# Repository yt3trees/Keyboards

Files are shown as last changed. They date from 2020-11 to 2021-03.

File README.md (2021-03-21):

# Limb44
Limb44, a split keyboard with 3x6 column staggered keys and 4 thumb keys.
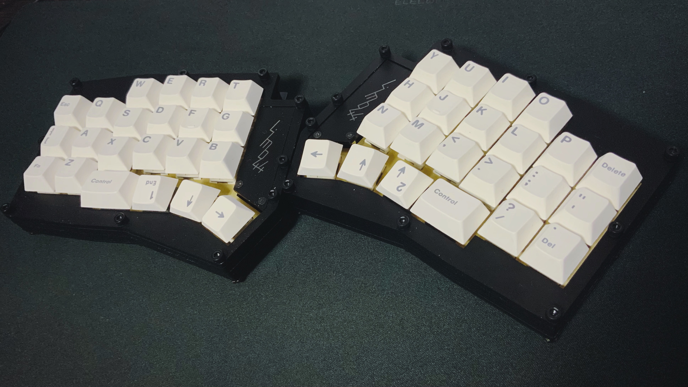
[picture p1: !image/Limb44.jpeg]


# Beryl32
Beryl32, a keyboard with 3x10 column staggered keys and 2 thumb keys.

Keyboard Maintainer: [yt3trees](https://github.com/yt3trees/)  [@yt3trees](https://twitter.com/yt3trees)
Firmware: [keyboards/limb44](https://github.com/yt3trees/qmk_firmware/tree/master/keyboards/limb44)

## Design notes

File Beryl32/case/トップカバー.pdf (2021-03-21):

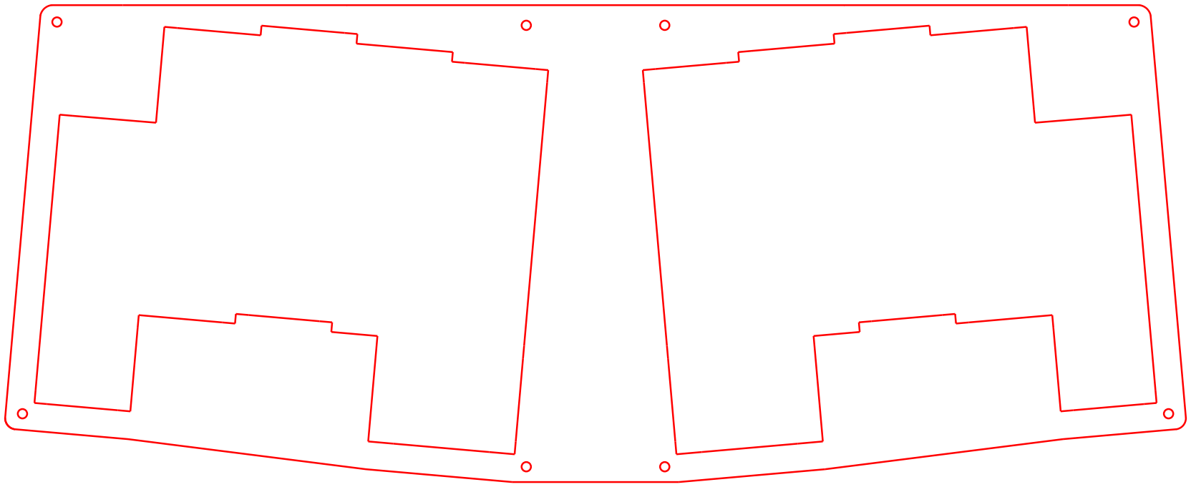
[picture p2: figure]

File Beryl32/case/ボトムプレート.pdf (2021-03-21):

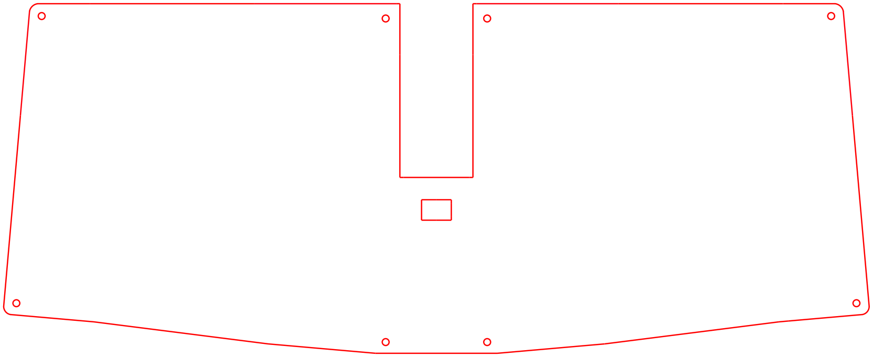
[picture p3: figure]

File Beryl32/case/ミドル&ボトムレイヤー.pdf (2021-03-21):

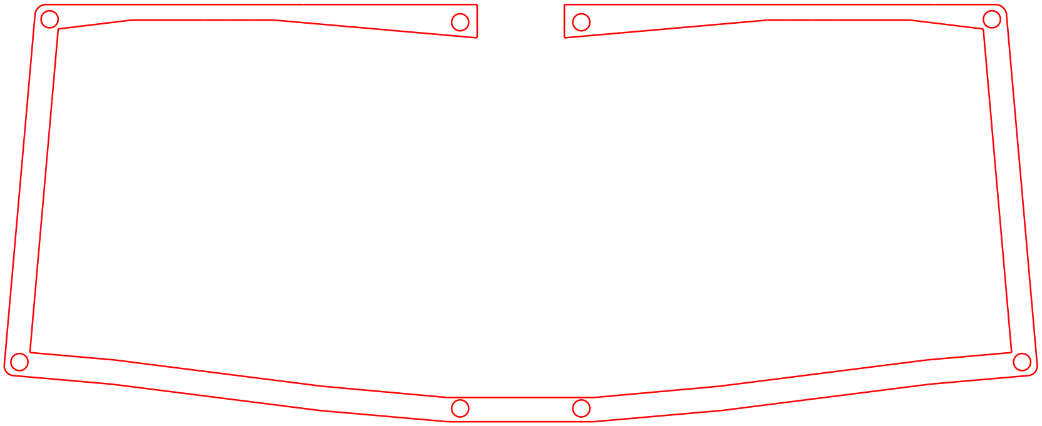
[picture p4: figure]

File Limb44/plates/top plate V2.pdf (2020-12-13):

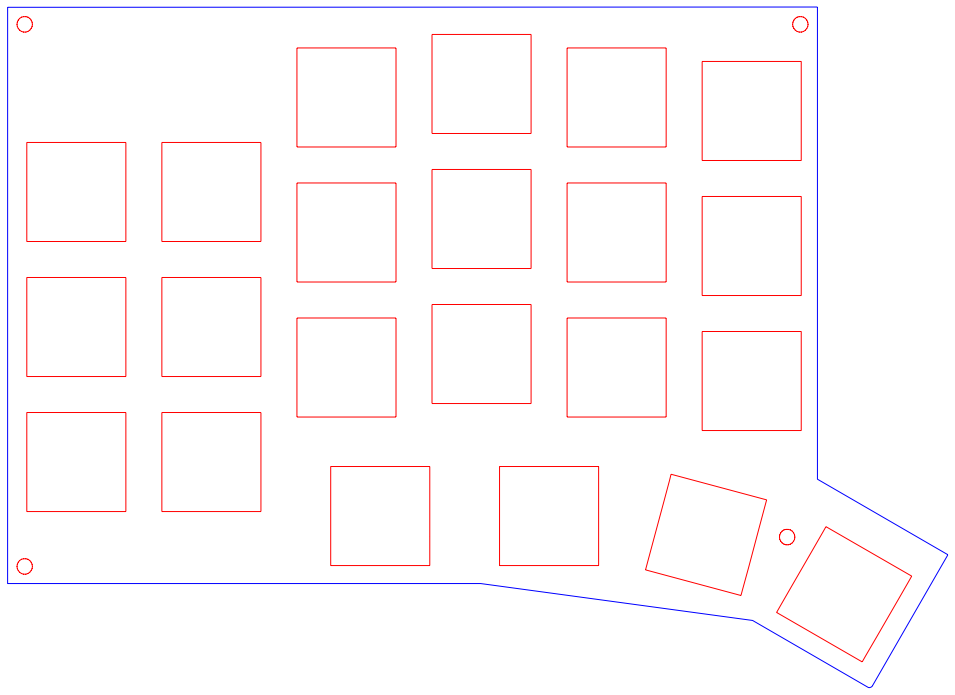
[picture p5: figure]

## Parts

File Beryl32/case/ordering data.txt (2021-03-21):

①トップカバー.pdf
　枚数：1枚
　カラー：ガラス色マット
　厚さ：5mm
　切断処理：鏡面仕上げ

②ミドル&ボトムレイヤー.pdf
　枚数：1枚
　カラー：ガラス色
　厚さ：5mm
　切断処理：鏡面仕上げ

③ミドル&ボトムレイヤー.pdf
　枚数：1枚
　カラー：ガラス色
　厚さ：2mm
　切断処理：鏡面仕上げ

④ボトムプレート.pdf
　枚数：1枚
　カラー：ガラス色マット
　厚さ：2mm
　切断処理：鏡面仕上げ

------
※②と③は同じpdfファイルです。

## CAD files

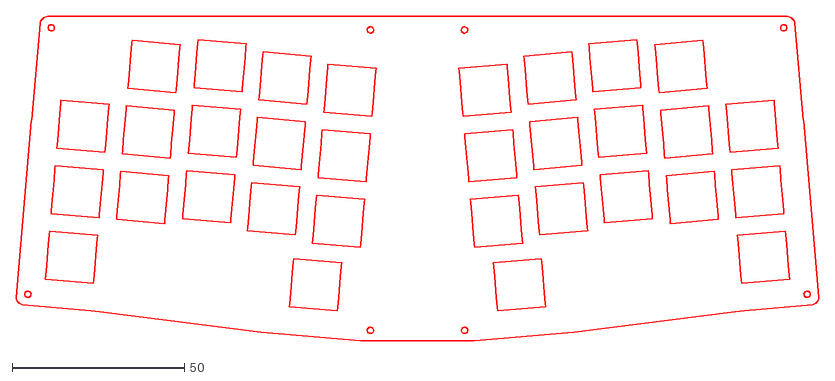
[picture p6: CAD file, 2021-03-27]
Beryl32/case/切断堂/マウントプレート.dxf
232.8 x 94.0

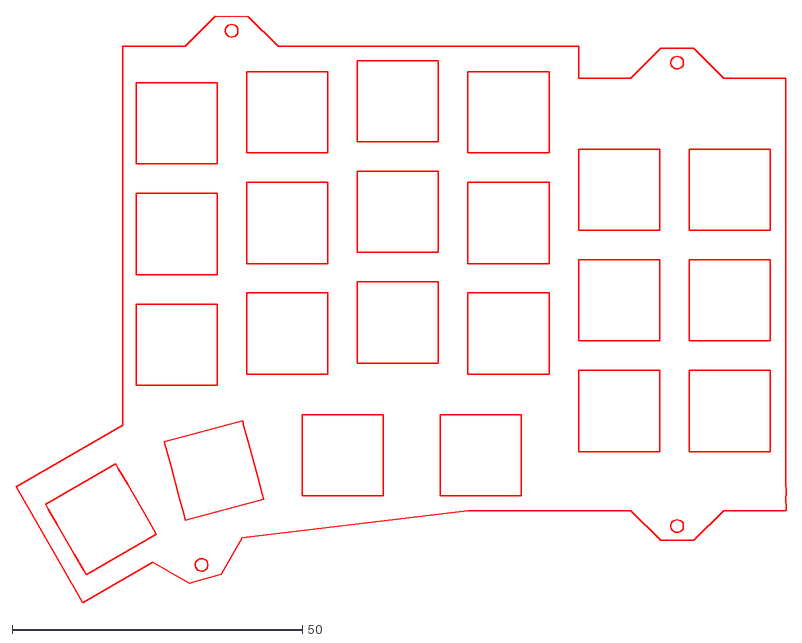
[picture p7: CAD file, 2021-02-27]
Limb44/plates/アクリル積層ver/V2/マウントプレート.dxf
132.6 x 100.9

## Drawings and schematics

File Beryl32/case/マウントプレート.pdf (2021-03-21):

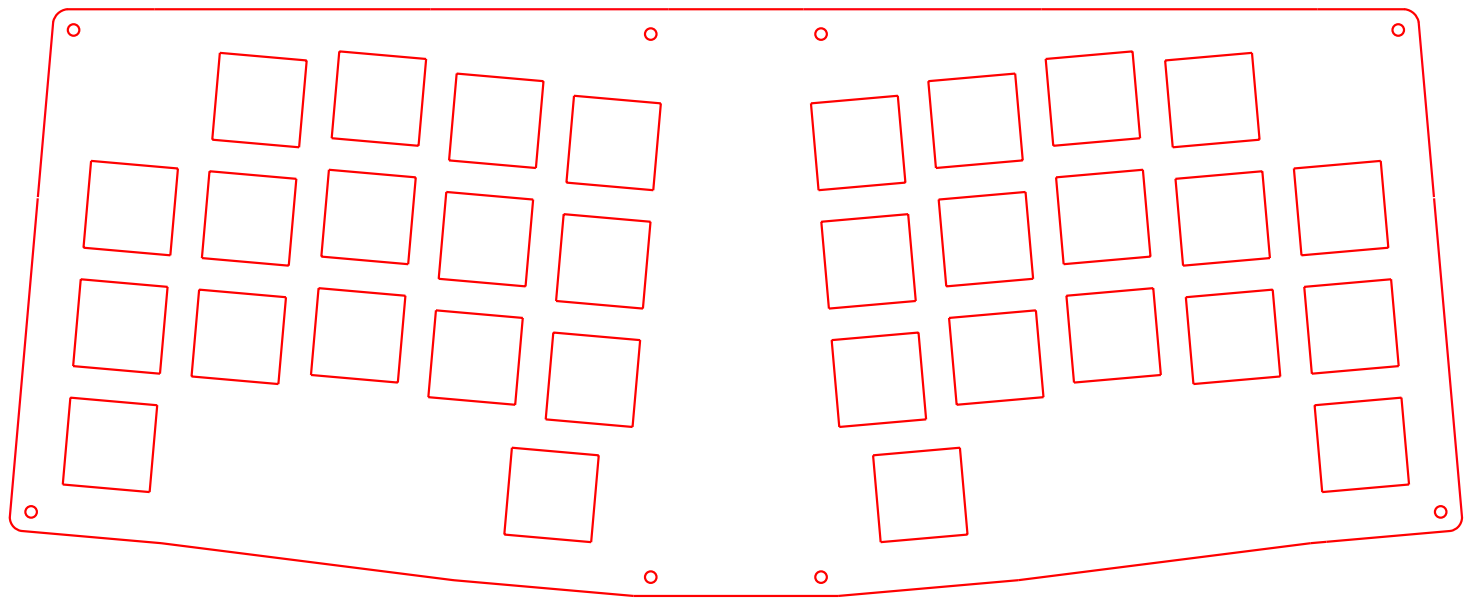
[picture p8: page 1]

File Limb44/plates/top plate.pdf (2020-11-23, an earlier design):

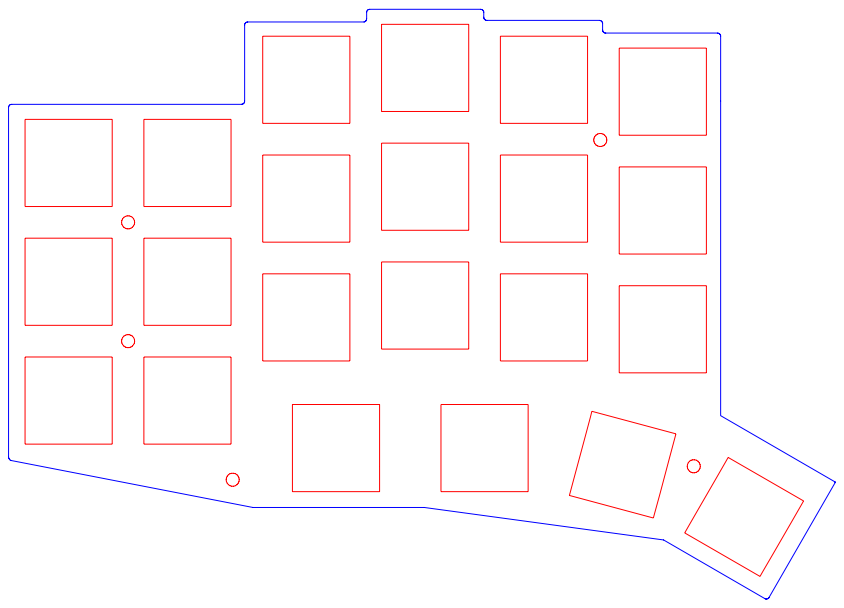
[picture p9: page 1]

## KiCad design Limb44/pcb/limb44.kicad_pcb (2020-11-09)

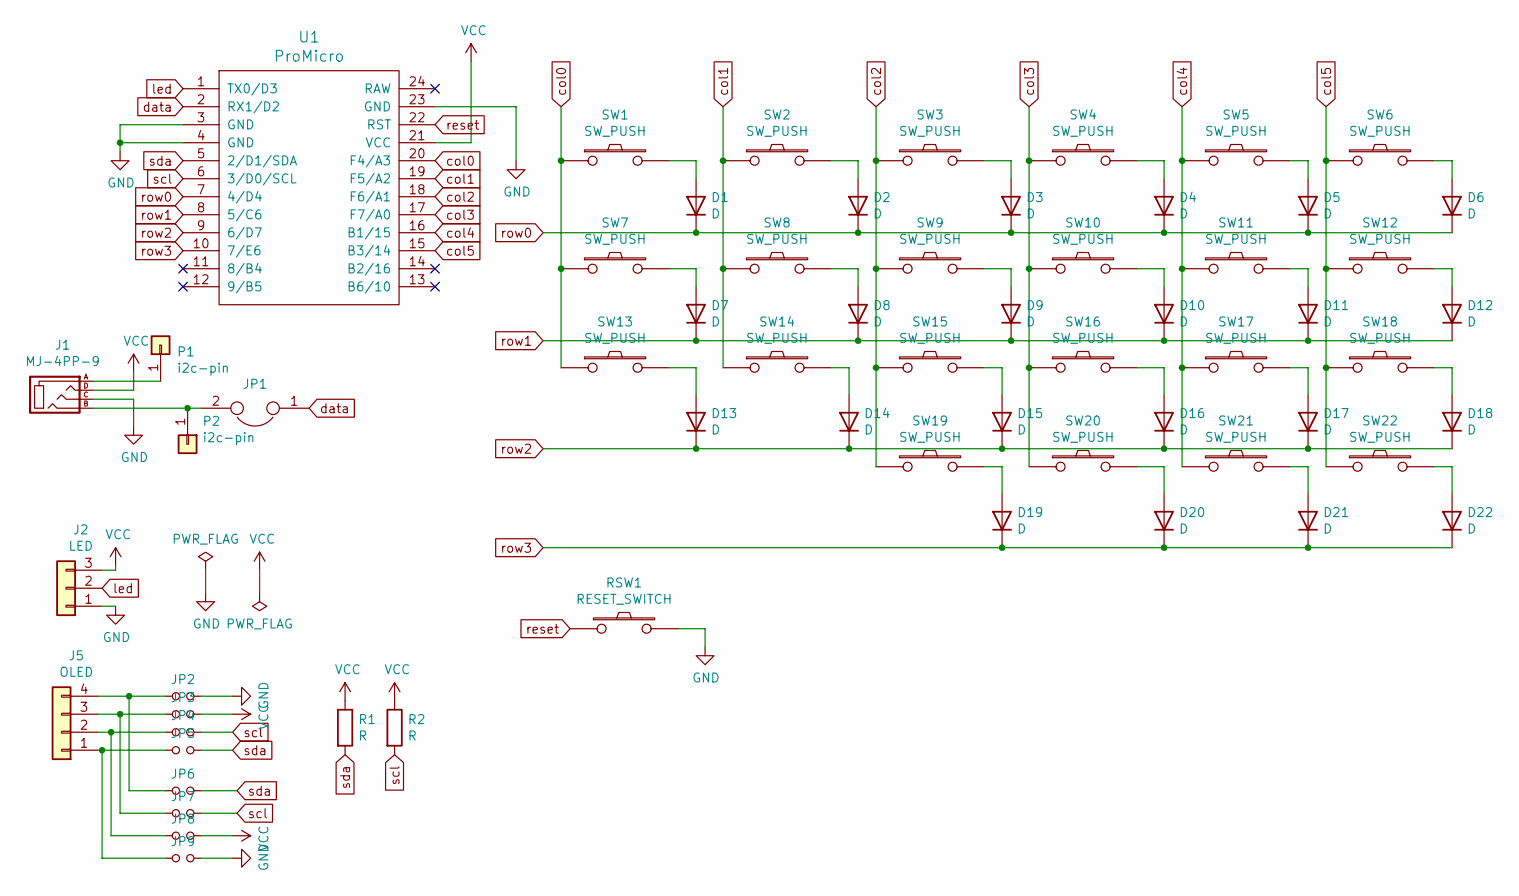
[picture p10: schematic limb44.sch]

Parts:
D1, D2, D3, D4, D5, D6, D7, D8, D9, D10, D11, D12, D13, D14, D15, D16, D17, D18, D19, D20, D21, D22: D; D3_SMD
J1: MJ-4PP-9
J2: LED; StripLED_rev
J5: OLED; OLED_v2
JP1: Jumper; JPC2
JP2, JP3, JP4, JP5, JP6, JP7, JP8, JP9: Jumper_NO_Small; Jumper
P1, P2: i2c-pin; 1pin_conn
R1, R2: R
RSW1: RESET_SWITCH; ResetSW
SW1, SW2, SW3, SW4, SW5, SW6, SW7, SW8, SW9, SW10, SW11, SW12, SW13, SW14, SW15, SW16, SW17, SW18, SW20, SW21, SW22: SW_PUSH; CherryMX_Choc_Hotswap
SW19: SW_PUSH; CherryMX_Choc_Hotswap_1.5u
U1: ProMicro; ProMicro_v2

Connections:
GND: J1.C, J2.1, JP2.2, JP9.2, RSW1.2, U1.3 (GND), U1.4 (GND), U1.23 (GND)
unnamed: D1.2 (A), SW1.2
unnamed: D2.2 (A), SW2.2
unnamed: D3.2 (A), SW3.2
unnamed: D4.2 (A), SW4.2
unnamed: D5.2 (A), SW5.2
unnamed: D6.2 (A), SW6.2
unnamed: D7.2 (A), SW7.2
unnamed: D8.2 (A), SW8.2
unnamed: D9.2 (A), SW9.2
unnamed: D10.2 (A), SW10.2
unnamed: D11.2 (A), SW11.2
unnamed: D12.2 (A), SW12.2
unnamed: D13.2 (A), SW13.2
unnamed: D14.2 (A), SW14.2
unnamed: D15.2 (A), SW15.2
unnamed: D16.2 (A), SW16.2
unnamed: D17.2 (A), SW17.2
unnamed: D18.2 (A), SW18.2
unnamed: D19.2 (A), SW19.2
unnamed: D20.2 (A), SW20.2
unnamed: D21.2 (A), SW21.2
unnamed: D22.2 (A), SW22.2
unnamed: J1.A, P1.1
unnamed: J1.B, JP1.2, P2.1
unnamed: J5.1, JP5.1, JP9.1
unnamed: J5.2, JP4.1, JP8.1
unnamed: J5.3, JP3.1, JP7.1
unnamed: J5.4, JP2.1, JP6.1
VCC: J1.D, J2.3, JP3.2, JP8.2, R1.1, R2.1, U1.21 (VCC)
col0: SW1.1, SW7.1, SW13.1, U1.20 (F4/A3)
col1: SW2.1, SW8.1, SW14.1, U1.19 (F5/A2)
col2: SW3.1, SW9.1, SW15.1, SW19.1, U1.18 (F6/A1)
col3: SW4.1, SW10.1, SW16.1, SW20.1, U1.17 (F7/A0)
col4: SW5.1, SW11.1, SW17.1, SW21.1, U1.16 (B1/15)
col5: SW6.1, SW12.1, SW18.1, SW22.1, U1.15 (B3/14)
data: JP1.1, U1.2 (RX1/D2)
led: J2.2, U1.1 (TX0/D3)
reset: RSW1.1, U1.22 (RST)
row0: D1.1 (K), D2.1 (K), D3.1 (K), D4.1 (K), D5.1 (K), D6.1 (K), U1.7 (4/D4)
row1: D7.1 (K), D8.1 (K), D9.1 (K), D10.1 (K), D11.1 (K), D12.1 (K), U1.8 (5/C6)
row2: D13.1 (K), D14.1 (K), D15.1 (K), D16.1 (K), D17.1 (K), D18.1 (K), U1.9 (6/D7)
row3: D19.1 (K), D20.1 (K), D21.1 (K), D22.1 (K), U1.10 (7/E6)
scl: JP4.2, JP7.2, R2.2, U1.6 (3/D0/SCL)
sda: JP5.2, JP6.2, R1.2, U1.5 (2/D1/SDA)

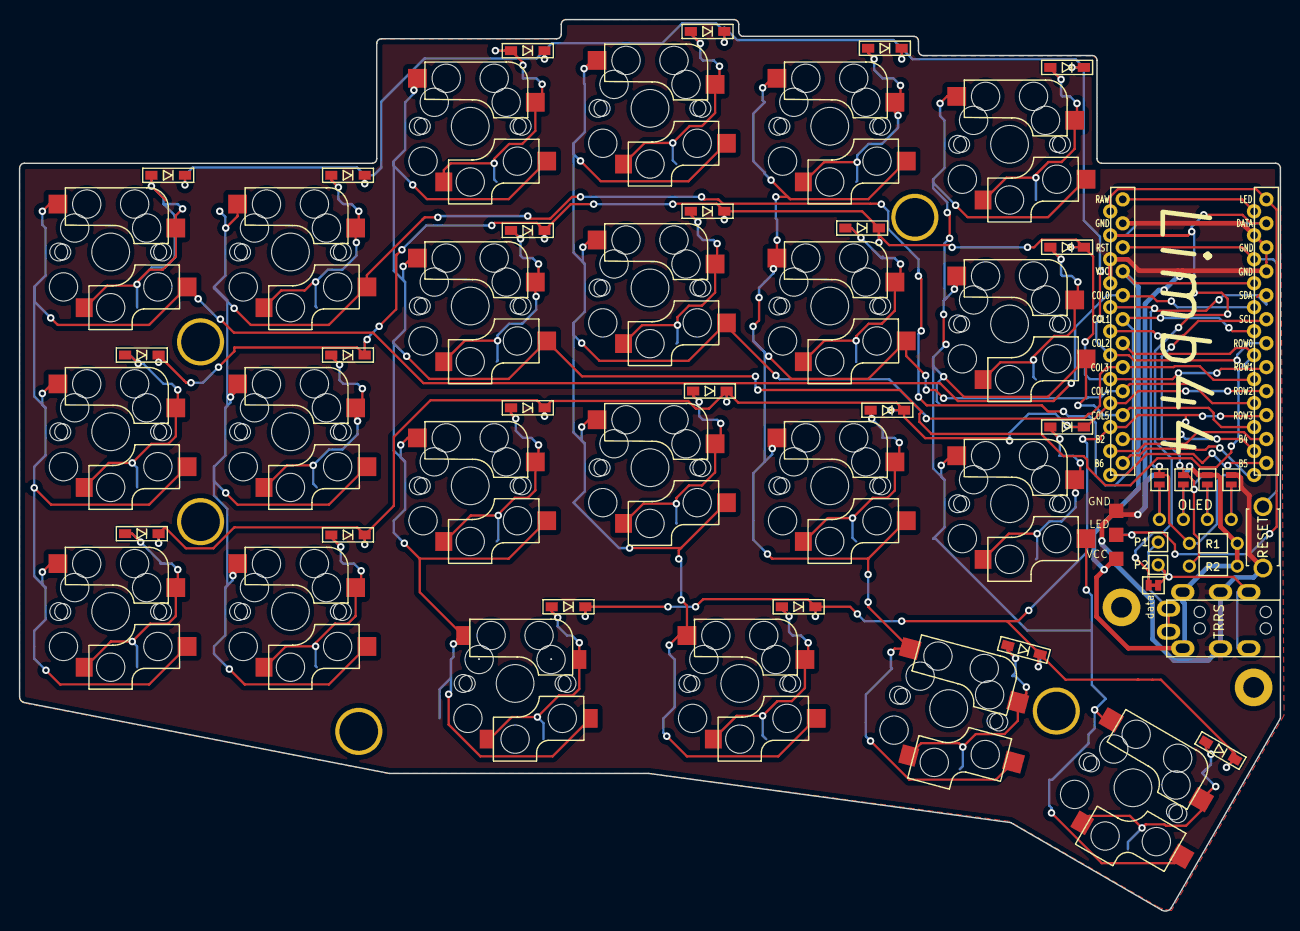
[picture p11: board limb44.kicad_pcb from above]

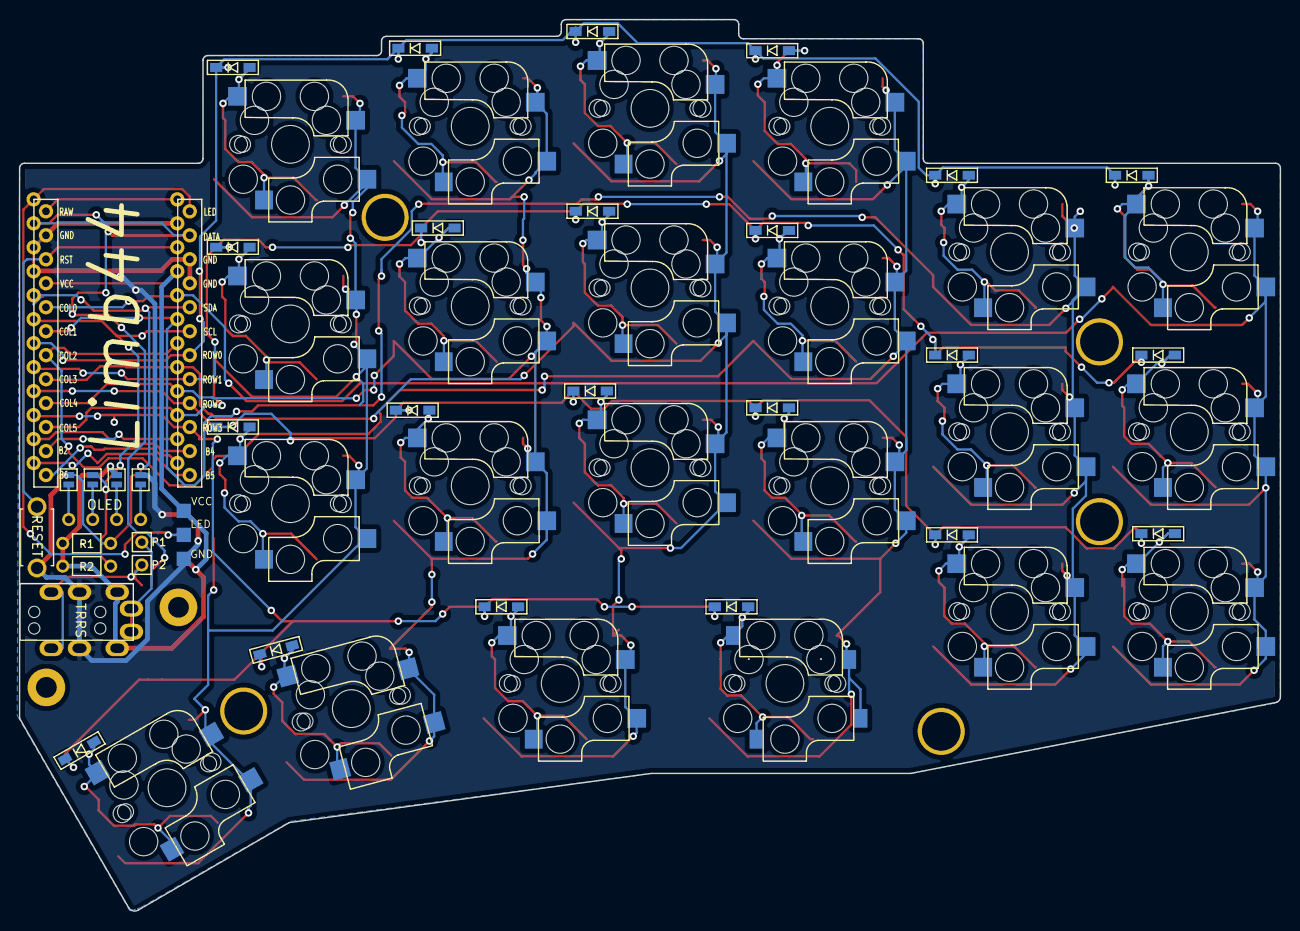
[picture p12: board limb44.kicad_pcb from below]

Board: 2 copper layers, 133.6 x 94.5 mm, 69 parts (4 on the bottom side), 45 nets.

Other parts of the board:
Ref**: Val**; HOLE
Ref**#2, Ref**#3, Ref**#4, Ref**#5, Ref**#6, Ref**#7: Val**; HOLE

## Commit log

2020-11-09 コミット
    [limb44.kicad_pcb, limb44.sch]
2020-11-09 add gerber
    [limb44-B_Cu.gbr, limb44-B_Mask.gbr, limb44-B_SilkS.gbr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]
2020-11-23 update top plate
2020-12-13 plate V2
2021-02-27 アクリル積層
    [マウントプレート.dxf]
2021-03-21 update folder structure and add Beryl32
    [Beryl32-B_Cu.gbr, Beryl32-B_Mask.gbr, Beryl32-B_SilkS.gbr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]
2021-03-27 add 注文データ
    [マウントプレート.dxf]
2021-07-11 add V2
    [マウントプレート.dxf]
